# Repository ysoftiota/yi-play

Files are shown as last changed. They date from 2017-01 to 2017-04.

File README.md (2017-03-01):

# YSoft IOTA Play
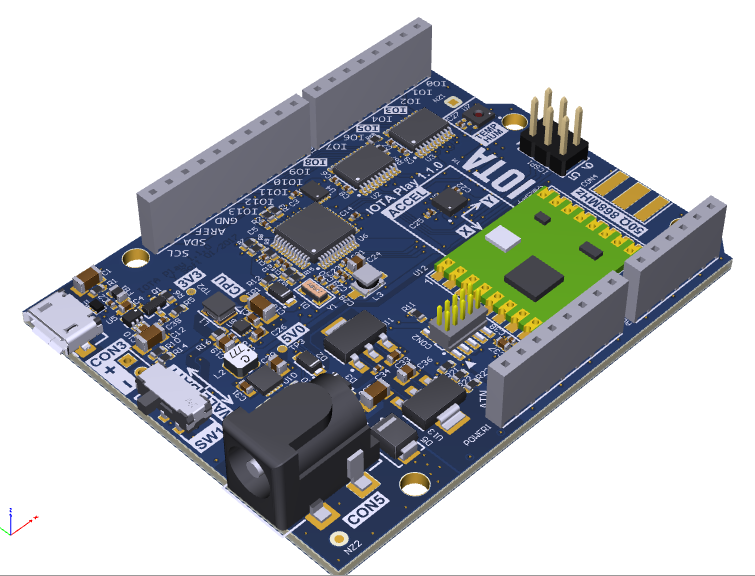
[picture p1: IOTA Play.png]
IOTA Play


## What is YSoft IOTA Play?

YSoft IOTA Play is [Arduino Zero](https://www.arduino.cc/en/Main/ArduinoBoardZero) ([Arduino M0](http://www.arduino.org/products/boards/arduino-m0)) clone with the following improvements:
* Two user LEDs
* Two user buttons
* Onboard Temperature + Humidity sensor [Silicon Labs SI7006-A20](https://www.silabs.com/products/sensors/humidity-sensors/Pages/si7013-20-21.aspx)
* Onboard 3 axis accelerometer [STM LIS3DE](http://www.st.com/en/mems-and-sensors/lis3de.html)
* Onboard crypto chip with ECC and RNG [Atmel ATECC508A](http://www.atmel.com/devices/atecc508a.aspx)
* Onboard ISM 868MHz transceiver [HopeRF RFM69](http://www.hoperf.com/rf_transceiver/modules/RFM69HW.html)
* 5V tolerant I/O on selected digital pins
  * Voltage level translator with possibility to use 5V output voltage using external pull-up (for CMOS logic)
* Enhanced power supplies
  * Optimized for battery operation - extremely low self-power consumption of power supplies
  * Designed for 2xAA, 2xAAA or other 3V alkaline cell operation (4V rechargeable lithium cells not supported)
  * <10uA complete board power consumption in standby (without power LEDs and peripheral voltages enabled)
  * 3.3V boost from 3V battery for core and peripherals
  * 3.3V peripheral voltage can be powered down in standby
  * 5V boost from 3V battery that can be powered down in standby
  * USB Host mode 5V supported in battery mode operation
* Manual switch between battery and USB/Power jack operation
* Most of functionality can be changed by onboard 0R resistors
  * Disable not needed peripherals
  * Disable not needed power supplies
  * Power consumption optimization
  * Set I/O pin for user application
* Additional SPI1 defined on pins 10,11,12,13 where Arduino UNO has got SPI

### Moreover:
* YSoft IOTA Play comes with configurable 3D printable box [How To](https://github.com/ysoftiota/yi-play/blob/master/Box/README.md)
* YSoft IOTA Play can be developed in Arduino IDE [How To](https://github.com/ysoftiota/yi-play-arduino)
* YSoft IOTA Play is open source and open hardware [Schematics](https://github.com/ysoftiota/yi-play/raw/master/IOTA_PlayBoard_1.1.0/Project%20Outputs%20for%20IOTA_PlayBoard_1.1.0/Schematic%20Print/IOTA_PlayBoard_1.1.0%20-%20Sche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), [3D PDF](https://github.com/ysoftiota/yi-play/raw/master/IOTA_PlayBoard_1.1.0/Project%20Outputs%20for%20IOTA_PlayBoard_1.1.0/3D%20View/IOTA_PlayBoard_1.1.0%20-%20Export%20PDF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), [PCB print](https://github.com/ysoftiota/yi-play/raw/master/IOTA_PlayBoard_1.1.0/Project%20Outputs%20for%20IOTA_PlayBoard_1.1.0/PCB%20Print/IOTA_PlayBoard_1.1.0%20-%20PCB%20Prin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), [Assembly drawing](https://github.com/ysoftiota/yi-play/raw/master/IOTA_PlayBoard_1.1.0/Project%20Outputs%20for%20IOTA_PlayBoard_1.1.0/PCB%20Print/IOTA_PlayBoard_1.1.0%20-%20Assembly%2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). See [IOTA_PlayBoard_1.1.0](https://github.com/ysoftiota/yi-play/tree/master/IOTA_PlayBoard_1.1.0) for complete PCB project.

# Limitations compared to Arduino Zero
* IOTA Play does not contain embedded EDBG debugger chip. [Atmel ICE debugger](http://www.atmel.com/tools/atatmel-ice.aspx) must be obtained separately if debugging is needed.
* LED(s) are on different pin, so use LED_BUILTIN and PIN_LED1 PIN_LED2 defines for accessing LEDs
* Maximum input voltage is 14V - however it starts as low as 5V
* Lower Amp rating of 5V (300mA) and 3.3V (200mA) voltage regulators which should be enough for normal applications. Power supplies are optimized for low-power battery operation, not for power hungry applications.
* Some pins are used by internal peripherals ([pin mapping](https://github.com/ysoftiota/yi-play/wiki/PinMapping), [pin mapping PDF](https://github.com/ysoftiota/yi-play/blob/master/IOTA_PlayBoard_1.1.0/IOTA%20Play%20board%201.1.0%20pin%20mapping.pdf)), therefore they cannot be used by anything else. However given peripheral can be disconnected by desoldering 0R resistors.
* Only one hardware serial port is supported and SerialUSB (defined as Serial) is used for Arduino monitor. If you need to access the hardware serial port then use SERIAL_PORT_HARDWARE define.

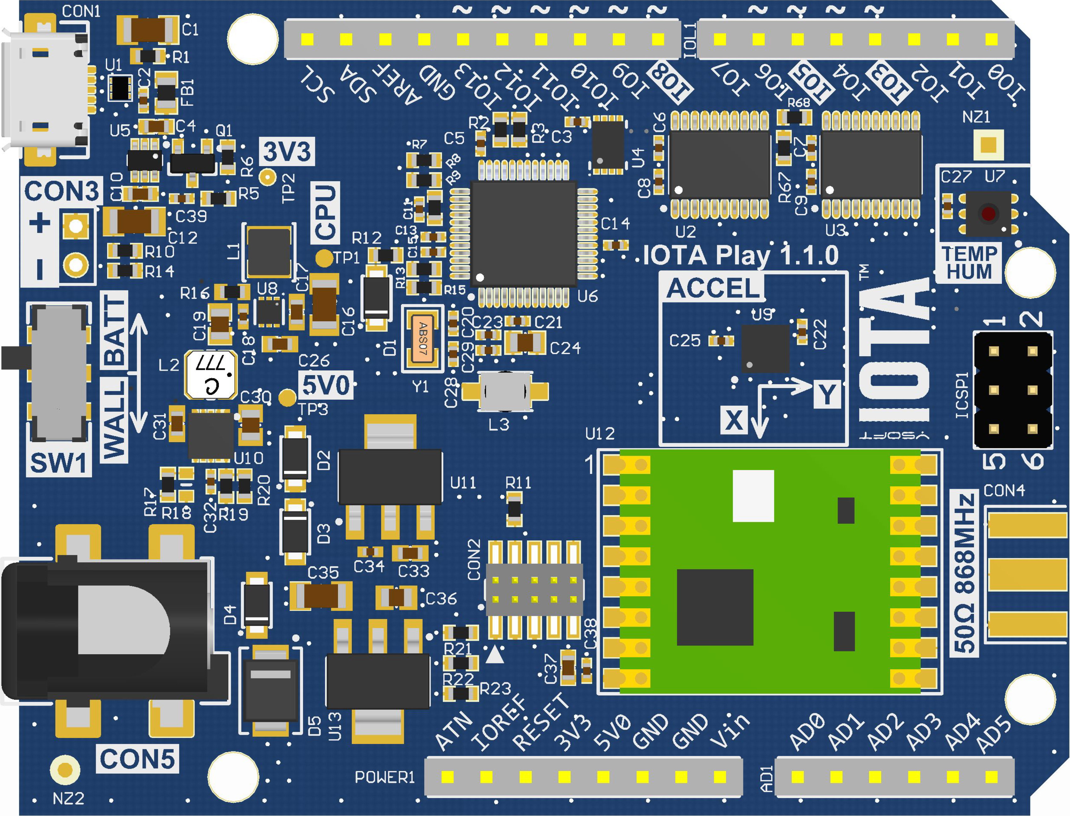
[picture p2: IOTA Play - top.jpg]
IOTA Play

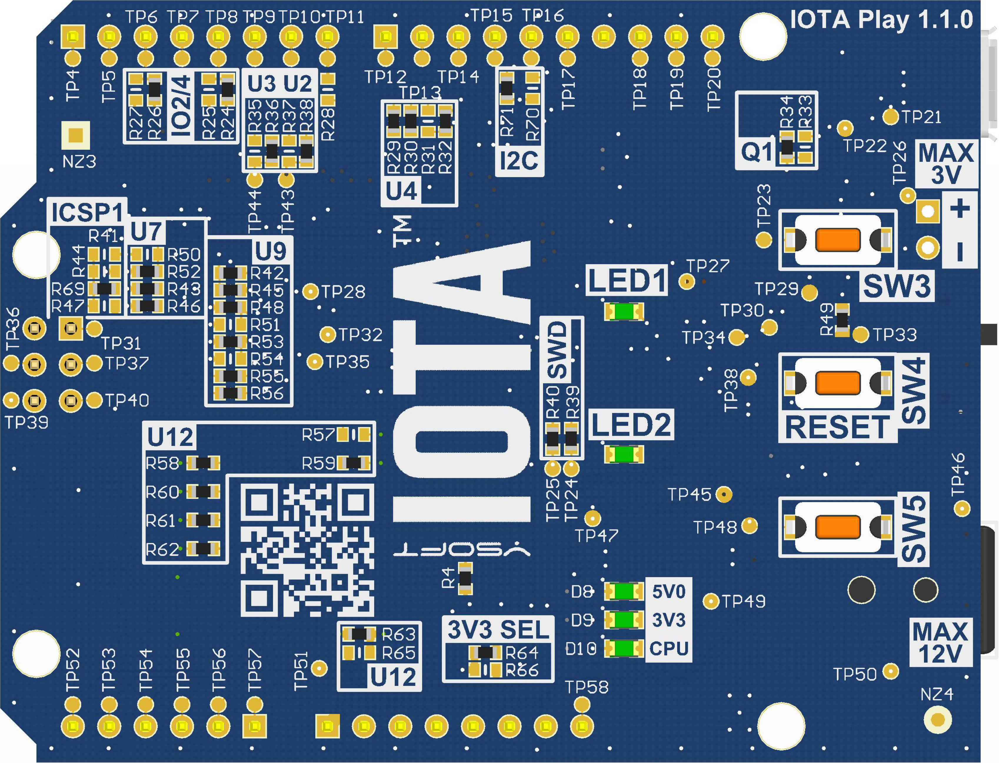
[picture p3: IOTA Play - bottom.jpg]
IOTA Play


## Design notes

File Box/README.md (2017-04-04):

# YSoft IOTA Play box
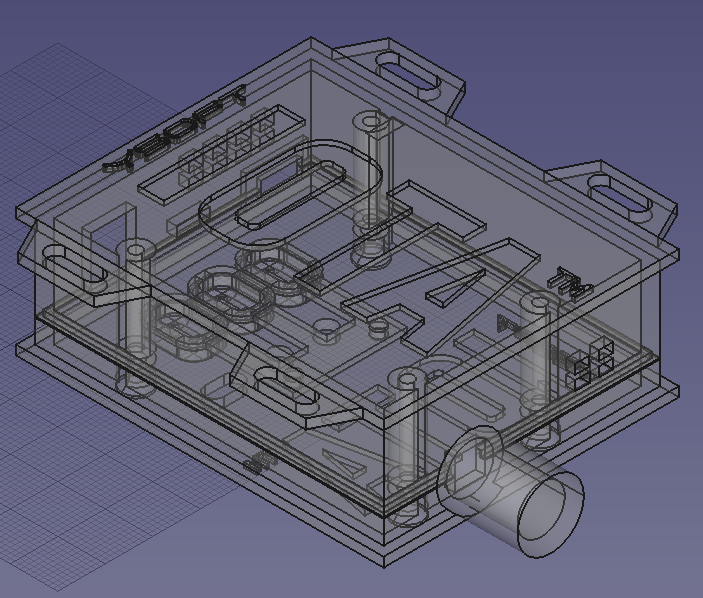
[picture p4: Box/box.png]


## Features
* The model is configurable - it contains all possible features for development or it can be used as a standalone box for outside use
  * configurable inner height
  * configurable spacers (for use with Arduino or prototyping shields)
  * buttons absent/present
  * led holes absent/present
  * logo absent/present
  * different connector holes absent/present
  * top/bottom mounting holes absent/present
* Printable on [YSoft be3D eDee](https://www.ysoft.com/en/be3d-edee-3dprinter) printers

## Manufacturing procedure
1. Download [stl/obj files](https://github.com/ysoftiota/yi-play/blob/master/Box/IOTA_Play_Box_1.1.zip) or export them using FreeCAD from [model](https://github.com/ysoftiota/yi-play/blob/master/Box/IOTA_Play_Box_1.1.FCStd). Please note that FreeCAD version 0.16 or higher is required.
1. Select the models to print in DeeControl, layout is recommended the following:
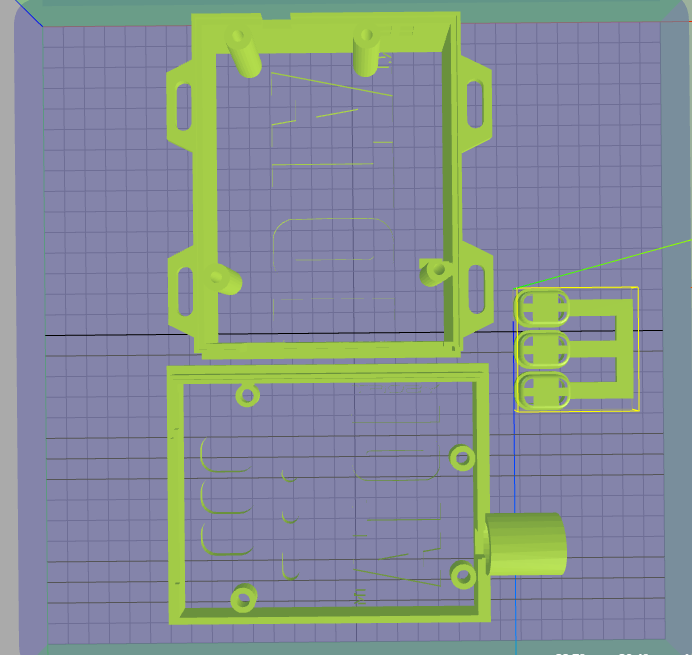
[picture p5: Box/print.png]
print

1. You can print either on Normal (150um) or Draft mode (200um)
1. Make sure you have supports off and that all the settings on the advanced tab are reset to default
1. Always thoroughly clean the print bed (by water and dry it afterwards) so that the box surface is nice and shiny
1. Apply the glue in uniform thin layer over the whole surface of the print bed. Make sure there are no spots without the glue because the large surfaces have tendencies to pick up.
1. The print will take 3-4h depending on quality selected
1. After printing it may be necessary to clean the buttons and button holes by a sharp knife so that the buttons move freely
1. If the buttons are not printed correctly, print them separately using slower speed or better quality.
1. You can glue the button holder on the centering pins or you can use soldering iron to melt them.
1. 4 screws are required. Screws [Bossard 2001225](https://eu.shop.bossard.com/mk/cz/10316/zavitorezne-srouby-vrtaci-srouby-zavitotvareci-srouby/srouby-do-termoplastu/bn-13576_srouby-pt-174-se-zapustnou-hlavou-s-kriz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) or longer for larger boxes [Bossard 3034352](https://eu.shop.bossard.com/mk/cz/10305/zavitorezne-srouby-vrtaci-srouby-zavitotvareci-srouby/srouby-do-termoplastu/bn-82427_srouby-se-zapustnou-hlavou-s-krizovou-dr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) are ideally suited.
1. Please remember to remove the white cover from the temperature/humidity sensor before use.
1. Enjoy your IOTA Play in the box

## Configuring the model
1. Open the FCStd file in FreeCad 0.16 or higher (in older versions you will not see the spreadsheet)
1. Open the model_parameters spread sheet from Combo View panel:
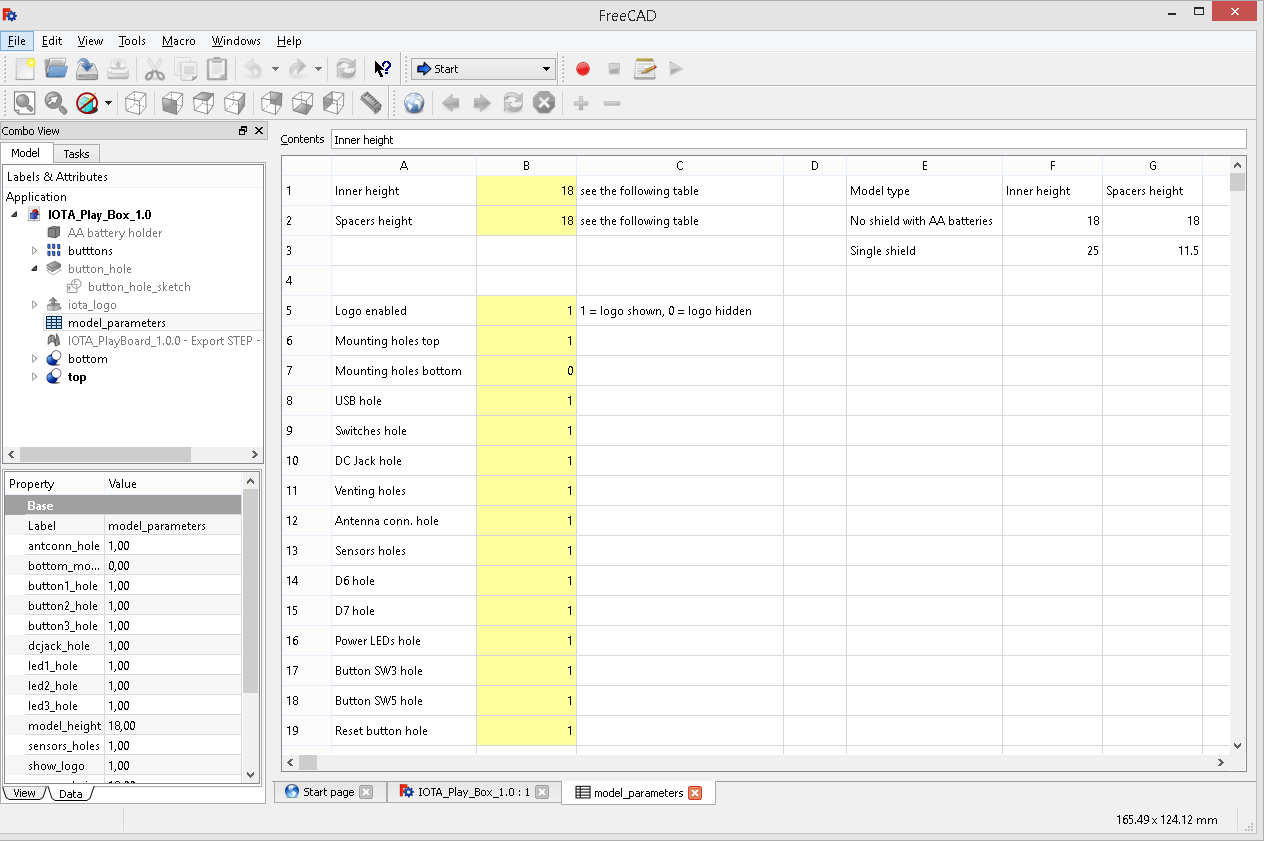
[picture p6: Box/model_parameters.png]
   
1. Select model height and which parts you need and which you don't. 1 means object enabled, 0 means object disabled.
1. Rewiew the changes you made, the model is transparent.
1. Click on 'top' part from Combo view (the part will turn green) and go to File -> Export. Select STL Mesh or Wavefront OBJ for the export format.
1. Repeat for 'bottom' and 'buttons' parts.
1. Follow the manufacturing procedure above

## Pictures
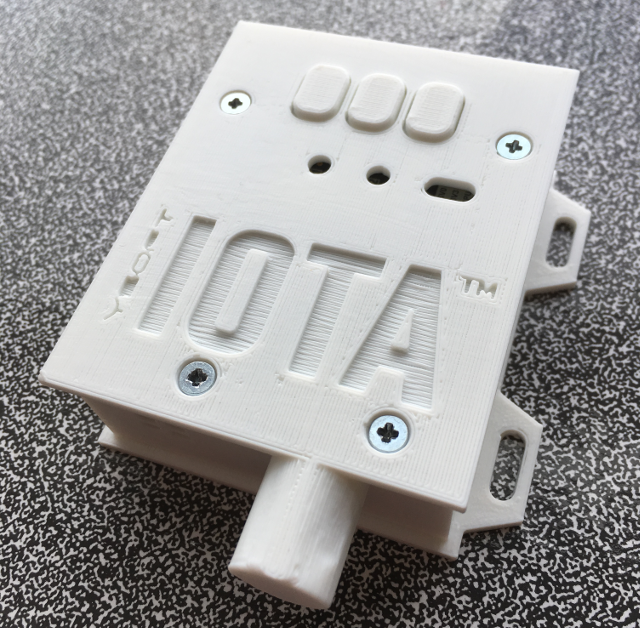
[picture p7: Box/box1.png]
 
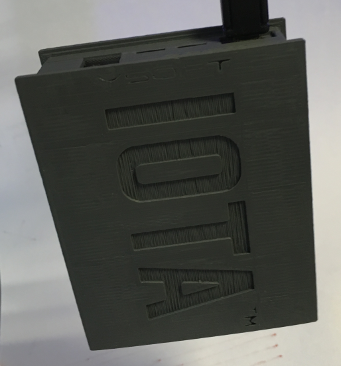
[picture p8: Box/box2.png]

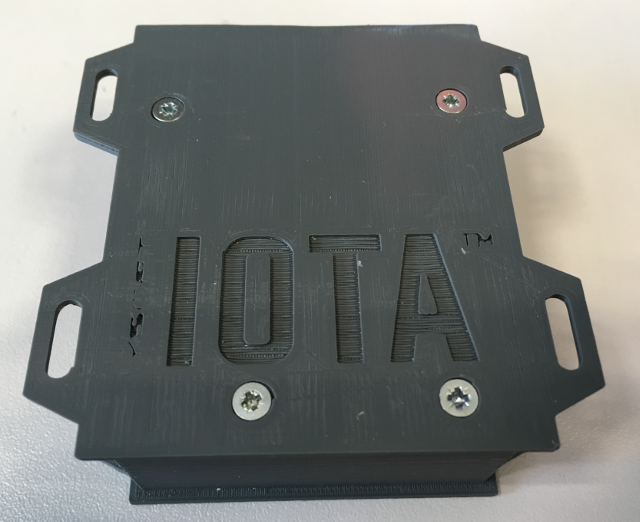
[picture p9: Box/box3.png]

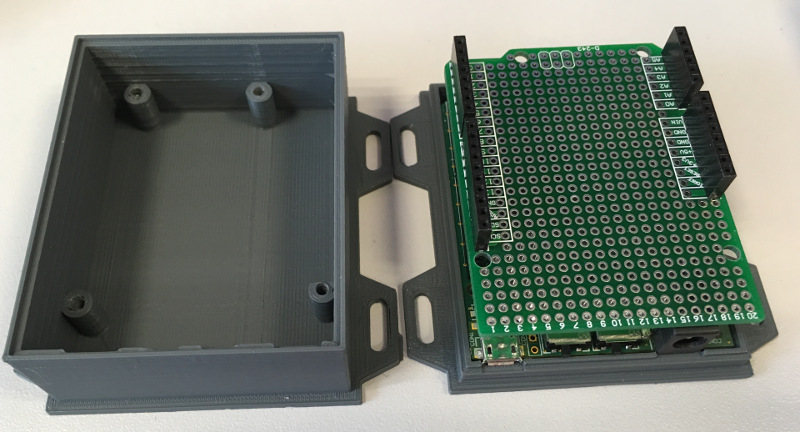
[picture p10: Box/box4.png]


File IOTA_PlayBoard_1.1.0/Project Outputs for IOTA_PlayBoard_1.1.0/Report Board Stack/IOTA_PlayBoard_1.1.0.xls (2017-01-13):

Board Stack Report
Stack Up |  | Layer Stack
Layer | Board Layer Stack | Name | Material | Thickness | Constant
1 |  | Top Paste
2 |  | Top Overlay
3 |  | Top Solder | Solder Resist | 0,010mm | 3,5
4 |  | Top Layer | Copper | 0,036mm
5 |  | Dielectric1 | IS400 - 2125 | 0,127mm | 4,2
6 |  | Internal Plane 1 | Copper | 0,036mm
7 |  | Dielectric 3 | IS400 | 1,200mm | 4,2
8 |  | Vcc Layer | Copper | 0,036mm
9 |  | Dielectric 4 | IS400 - 2125 | 0,127mm | 4,2
10 |  | Bottom Layer | Copper | 0,036mm
11 |  | Bottom Solder | Solder Resist | 0,010mm | 3,5
12 |  | Bottom Overlay
13 |  | Bottom Paste
 | Height : 1,618mm

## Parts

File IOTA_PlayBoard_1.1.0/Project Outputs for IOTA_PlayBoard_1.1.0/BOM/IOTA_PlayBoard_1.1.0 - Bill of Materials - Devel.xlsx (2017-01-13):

Designator | Comment | Description | Helios ID | Quantity | Footprint | DocumentName
AD1 | BL806G | Pinheader Female 6 pin 2.54mm | CON-BL806G | 1 | HDR1X06F | 01 - Connectors.SchDoc
C1 | 1nF/2kV | SMD Ceramic Capacitor 1206 1nF/2kV | CAP-1206 1nF/2kV | 1 | C-1206 | 01 - Connectors.SchDoc
C2, C3, C5, C6, C7, C8, C9, C11, C14, C15, C18, C21, C22, C23, C25, C27, C32, C38 | 100nF/16V | SMD Ceramic Capacitor 0402 100nF/16V | CAP-0402 100nF/16V | 18 | C-0402 | 01 - Connectors.SchDoc, 04 - Peripherals.SchDoc, 03 - CPU.SchDoc, 01 - Connectors.SchDoc, 01 - Connectors.SchDoc, 01 - Connectors.SchDoc, 01 - Connectors.SchDoc, 03 - CPU.SchDoc, 03 - CPU.SchDoc, 03 - CPU.SchDoc, 02 - Power.SchDoc, 03 - CPU.SchDoc, 04 - Peripherals.SchDoc, 01 - Connectors.SchDoc, 04 - Peripherals.SchDoc, 04 - Peripherals.SchDoc, 02 - Power.SchDoc, 04 - Peripherals.SchDoc
C4, C10, C31 | 2.2uF/16V/X5R | SMD Ceramic Capacitor 0603 2.2uF/16V/X5R | CAP-0603 2.2uF/16V/X5R | 3 | C-0603 | 02 - Power.SchDoc
C12, C16 | 100u/10V X5R | SMD Ceramic Capacitor 1206 100u/10V X5R | CAP-1206 100u/10V X5R | 2 | C-1206 | 01 - Connectors.SchDoc, 02 - Power.SchDoc
C13, C29, C34 | 1uF/10V/X5R | SMD Ceramic Capacitor 0402 1uF/10V/X5R | CAP-0402 1uF/10V/X5R | 3 | C-0402 | 03 - CPU.SchDoc, 01 - Connectors.SchDoc, 02 - Power.SchDoc
C17, C26, C33, C37 | 10uF/6.3V/X5R | SMD Ceramic Capacitor 0603 10uF/6.3V/X5R | CAP-0603 10uF/6.3V/X5R | 4 | C-0603 | 02 - Power.SchDoc, 02 - Power.SchDoc, 02 - Power.SchDoc, 04 - Peripherals.SchDoc
C19, C24, C30, C36 | 10u/10V | SMD Ceramic Capacitor 0805 10u/10V | CAP-0805 10u/10V | 4 | C-0805 | 02 - Power.SchDoc, 03 - CPU.SchDoc, 02 - Power.SchDoc, 02 - Power.SchDoc
C20, C28 | 22pF | SMD Ceramic Capacitor 0402 22pF | CAP-0402 22pF | 2 | C-0402 | 03 - CPU.SchDoc
C35 | 22uF/25V/X5R | SMD Ceramic Capacitor 1206 22uF/25V/X5R | CAP-1206 22u/25V/X5R | 1 | C-1206 | 02 - Power.SchDoc
C39 | 10nF/10V | SMD Ceramic Capacitor 0402 10nF/10V | CAP-0402 10nF/10V | 1 | C-0402 | 02 - Power.SchDoc
CON1 | 10104111-0001LF | Micro USB AB SMD | CON-10104111-0001LF | 1 | 10104111-0001LF | 01 - Connectors.SchDoc
CON2 | CH52102M100 | 2x5pin dual row male header 1.27 mm | CON-CH52102M100-0P | 1 | CH52102M100 | 01 - Connectors.SchDoc
CON3 | PAD1G02 | 1x2pin single row pads, 2.54mm | CON-PAD1G02 | 1 | HDR1X02S | 01 - Connectors.SchDoc
CON5 | PJ-002AH-SMT | Power Jack 2.1x5.5mm | CON-PJ-002AH-SMT | 1 | PJ-002AH-SMT | 01 - Connectors.SchDoc
D1, D2, D3, D4 | MBR140SFT | Schottky Power Rectifier MBR140SFT | DIO-MBR140SFT | 4 | SOD-123FL | 03 - CPU.SchDoc, 02 - Power.SchDoc, 02 - Power.SchDoc, 02 - Power.SchDoc
D5 | SM6T15A | Transil 15V | DIO-SM6T15A | 1 | D-SMB | 02 - Power.SchDoc
D8, D9, D10, LED1, LED2 | LED G | LED; SMD; 0805; zelená; 1.3-3mcd; 2.0x1.25x1,1mm; 120°; 1.9V; 2mA | DIO-KP-2012LSGC | 5 | LED-0805 GREEN | 03 - CPU.SchDoc
FB1 | BLM21PG221SN1D | Chip Ferrite Bead 220R/2A 0805 | IND-BLM21PG221SN1D | 1 | FB-0805 | 01 - Connectors.SchDoc
ICSP1 | S2G06 | 2x6pin dual row header, 2.54mm | CON-S2G06 | 1 | HDR2X06 | 01 - Connectors.SchDoc
IOH1 | BL810G | Pinheader Female 10 pin 2.54mm | CON-BL810G | 1 | HDR1X10F | 01 - Connectors.SchDoc
IOL1, POWER1 | BL808G | Pinheader Female 8 pin 2.54mm | CON-BL808G | 2 | HDR1X08F | 01 - Connectors.SchDoc
L1 | SRN3015-4R7M | Shielded inductor 4.7uH/1.2A 3x3mm | IND-SRN3015-4R7M | 1 | TLU-SRN3015 | 02 - Power.SchDoc
L2 | LPS3015-152MRC | Shielded inductor 1.5uH/1.3A 3x3mm | IND-LPS3015-152MRC | 1 | LPS3015 | 02 - Power.SchDoc
L3 | LQH32CN100K23L | Unshielded Wirewound Inductor 10uH/300mA/572mOhm 3.2x2.5mm | IND-LQH32CN100K23L | 1 | LQH32C | 03 - CPU.SchDoc
NZ1, NZ3 | Fiducial Rectangle | Fiducial Rectangle | x004 | 2 | Fiducial Rectangle | 01 - Connectors.SchDoc
NZ2, NZ4 | Fiducial Circle | Fiducial Circle | x005 | 2 | Fiducial Circle | 01 - Connectors.SchDoc
Q1 | FDV303N | N-channel Digital FET 25 V, 680 mA | TRA-FDV303N | 1 | SOT23-3L | 02 - Power.SchDoc
R1 | 100R 1% | SMD Resistor 0603 100R 1% | RES-0603 100R 1% | 1 | R-0603 | 01 - Connectors.SchDoc
R2, R3, R7, R8, R11, R12 | 10k | SMD Resistor 0603 10k | RES-0603 10k | 6 | R-0603 | 01 - Connectors.SchDoc, 01 - Connectors.SchDoc, 03 - CPU.SchDoc, 03 - CPU.SchDoc, 01 - Connectors.SchDoc, 03 - CPU.SchDoc
R4, R24, R26, R29, R30, R32, R34, R36, R38, R39, R40, R42, R43, R45, R46, R48, R49, R52, R53, R55, R56, R58, R59, R60, R61, R62, R63, R64, R69, R71 | 0R | SMD Resistor 0603 0R | RES-0603 0R | 30 | R-0603 | 01 - Connectors.SchDoc, 01 - Connectors.SchDoc, 01 - Connectors.SchDoc, 04 - Peripherals.SchDoc, 04 - Peripherals.SchDoc, 04 - Peripherals.SchDoc, 02 - Power.SchDoc, 01 - Connectors.SchDoc, 01 - Connectors.SchDoc, 03 - CPU.SchDoc, 03 - CPU.SchDoc, 04 - Peripherals.SchDoc, 04 - Peripherals.SchDoc, 04 - Peripherals.SchDoc, 04 - Peripherals.SchDoc, 04 - Peripherals.SchDoc, 02 - Power.SchDoc, 04 - Peripherals.SchDoc, 04 - Peripherals.SchDoc, 04 - Peripherals.SchDoc, 04 - Peripherals.SchDoc, 04 - Peripherals.SchDoc, 04 - Peripherals.SchDoc, 04 - Peripherals.SchDoc, 04 - Peripherals.SchDoc, 04 - Peripherals.SchDoc, 04 - Peripherals.SchDoc, 01 - Connectors.SchDoc, 01 - Connectors.SchDoc, 01 - Connectors.SchDoc
R5, R6, R20 | 887k 1% | SMD Resistor 0603 887k 1% | RES-0603 887k 1% | 3 | R-0603 | 02 - Power.SchDoc
R9, R16 | 470R | SMD Resistor 0603 470R | RES-0603 470R | 2 | R-0603 | 03 - CPU.SchDoc, 02 - Power.SchDoc
R10, R17 | 1.87M 1% | SMD Resistor 0603 1.87M 1% | RES-0603 1.87M 1% | 2 | R-0603 | 02 - Power.SchDoc
R13, R15, R22, R23 | 1k 1% | SMD Resistor 0603 1k 1% | RES-0603 1k 1% | 4 | R-0603 | 03 - CPU.SchDoc
R14 | 604k 1% | SMD Resistor 0603 604k 1% | RES-0603 604k 1% | 1 | R-0603 | 02 - Power.SchDoc
R19 | 100k 1% | SMD Resistor 0603 100k 1% | RES-0603 100k 1% | 1 | R-0603 | 02 - Power.SchDoc
R21 | 1.5k | SMD Resistor 0603 1k5 | RES-0603 1k5 | 1 | R-0603 | 03 - CPU.SchDoc
R67, R68 | 200k | SMD Resistor 0603 200k | RES-0603 200k | 2 | R-0603 | 01 - Connectors.SchDoc
SW1 | JS202011JAQN | Slide Switch DPDT Surface Mount, Right Angle | SWI-JS202011JAQN | 1 | JS202011JAQN | 02 - Power.SchDoc
SW3, SW4, SW5 | DTSM31N | SMT tactile switch, 2 pin | SWI-DTSM31N | 3 | DTSM31N | 03 - CPU.SchDoc
U1 | TPD4S012DRY | 4-Channel USB ESD Solution with Power Clamp | IC-TPD4S012DRYR | 1 | DRY6 | 01 - Connectors.SchDoc
U2, U3 | LSF0108PWR | 8-Bit Bidirectional Voltage-Level Translator For Open-Drain And Push-Pull Application | IC-LSF0108PWR | 2 | TSOP65P640X120-20L | 01 - Connectors.SchDoc
U4 | ATECC508A | CryptoAuthentication Device with 10Kb EEPROM | IC-ATECC508A-MAHDA-S | 1 | SON50P300X60_HS-9N | 04 - Peripherals.SchDoc
U5 | SIP32431DR3 | 1 A Slew Rate Controlled Load Switch with Reverse Blocking SOT-363 | IC-SIP32431DR3-T1GE3 | 1 | SOT65P210X110-6L | 02 - Power.SchDoc
U6 | ATSAMD21G18A-AUT | ARM® Cortex®-M0+ SAM D21G Microcontroller IC 32-Bit 48MHz 256KB (256K x 8) FLASH 48-TQFP (7x7) | IC-ATSAMD21G18A-AUT | 1 | TSQFP50P900X900X160-48L | 03 - CPU.SchDoc
U7 | SI7006-A20 | I2C Humidity and Temperature Sensor | IC-SI7006-A20-IM1 | 1 | DFN100P300X300X60_HS-7N - duplicate | 04 - Peripherals.SchDoc
U8 | TPS610986 | Ultra-Low Quiescent Current Synchronous Boost with Integrated Load Switch | IC-TPS610986DSE | 1 | SON50P150X80-6N | 02 - Power.SchDoc
U9 | LIS3DETR | Accelerometer X, Y, Z | IC-LIS3DETR | 1 | PQFN50P300X300X100-16N | 04 - Peripherals.SchDoc
U10 | TPS63030DSK | High Efficient Single Inductor Buck-Boost Converter with 1-A Switches | IC-TPS63030DSKR | 1 | DSK10-2000X1200TP_V | 02 - Power.SchDoc
U11 | AP7361-33E | Linear Voltage Regulator IC Positive Fixed 1 Output 3.3V 1A SOT-223 | IC-AP7361-33E-13 | 1 | SOT230P700X180-4N | 02 - Power.SchDoc
U12 | RFM69HW-868 | RFM69HW ISM TRANSCEIVER MODULE | RF-RFM69HW-868S2 | 1 | RFM69HW-XXXS2 | 04 - Peripherals.SchDoc
U13 | NCP1117LPST50 | 1.0A, 5V Low-Dropout Positive Voltage Regulator | IC-NCP1117LPST50T3G | 1 | SOT230P700X180-4N | 02 - Power.SchDoc
Y1 | 32768Hz | Crystal 32768 Hz SMD, package 3.2x1.5mm | CRY-ABS07-32.768KHZ-T | 1 | ABS07 | 03 - CPU.SchDoc

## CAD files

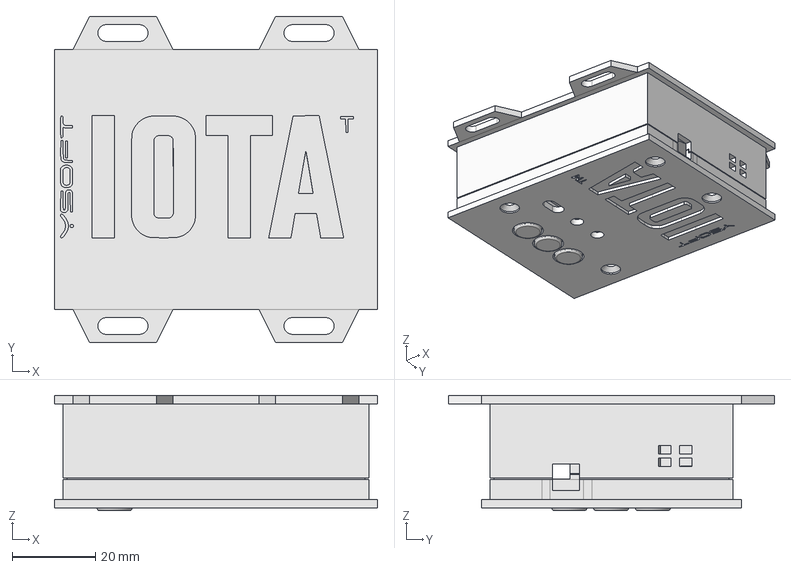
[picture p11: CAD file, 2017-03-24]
Box/IOTA_Play_Box_1.1.FCStd
77.4 x 78.2 x 27.6 mm
butttons
bottom
top

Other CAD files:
Box/IOTA_Play_Box_1.0.FCStd

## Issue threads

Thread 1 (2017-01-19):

QR code is in negative colors and cannot be read

setnicka, 2017-01-19:
The QR code at the bottom of the board is in negative colors.

Many QR code readers (for example popular [Barcode Scanner](https://play.google.com/store/apps/details?id=com.google.zxing.client.android), [QR & Barcode Scanner](https://play.google.com/store/apps/details?id=com.gamma.scan) for Android and many others) cannot read inverted QR codes.

QR code should be printed in inverted colors - blue on white background.

And maybe link should be https://github.com/ysoftiota/yi-play (not only https://github.com/ysoftiota).

VelkyVenik, 2017-01-19:
I have no experiences with QR code readers, mine just works :) But I agree with the link, that it should be https://github.com/ysoftiota/yi-play

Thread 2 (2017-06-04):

Thermometer example

borissuska, 2017-06-04:
#import <i2cdetect.h> is not necessary on line 10.

Is `data[3]`correct on line 48? The array is defined as `unsigned int data[2];` on line 27.

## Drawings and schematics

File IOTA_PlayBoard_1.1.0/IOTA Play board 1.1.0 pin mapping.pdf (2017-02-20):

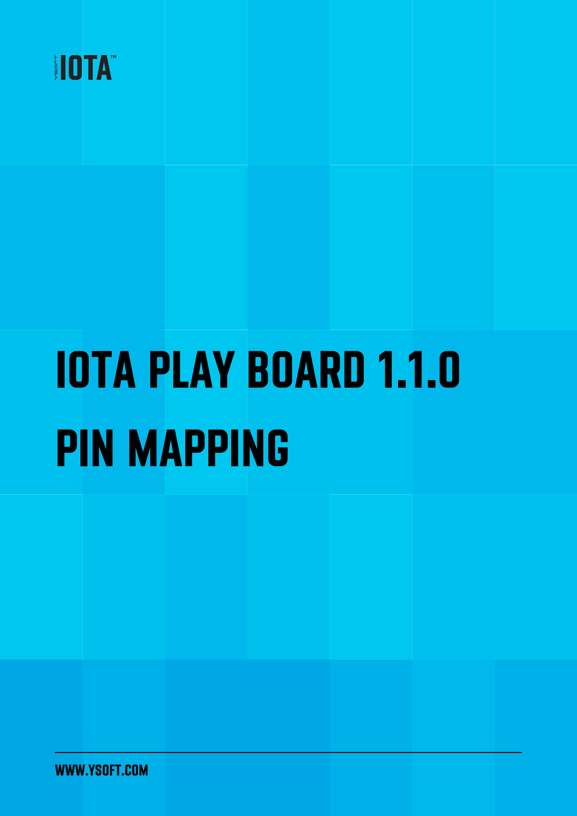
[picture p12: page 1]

# IOTA PLAY BOARD 1.1.0 PIN MAPPING

## WWW.YSOFT.COM

CONTENT 1 | Arduino Connectors

3

### 2 SPI Connector

5

### 3 IOTA Play specific

6

### 4 Complete PIN mapping

7

# 1 ARDUINO CONNECTORS

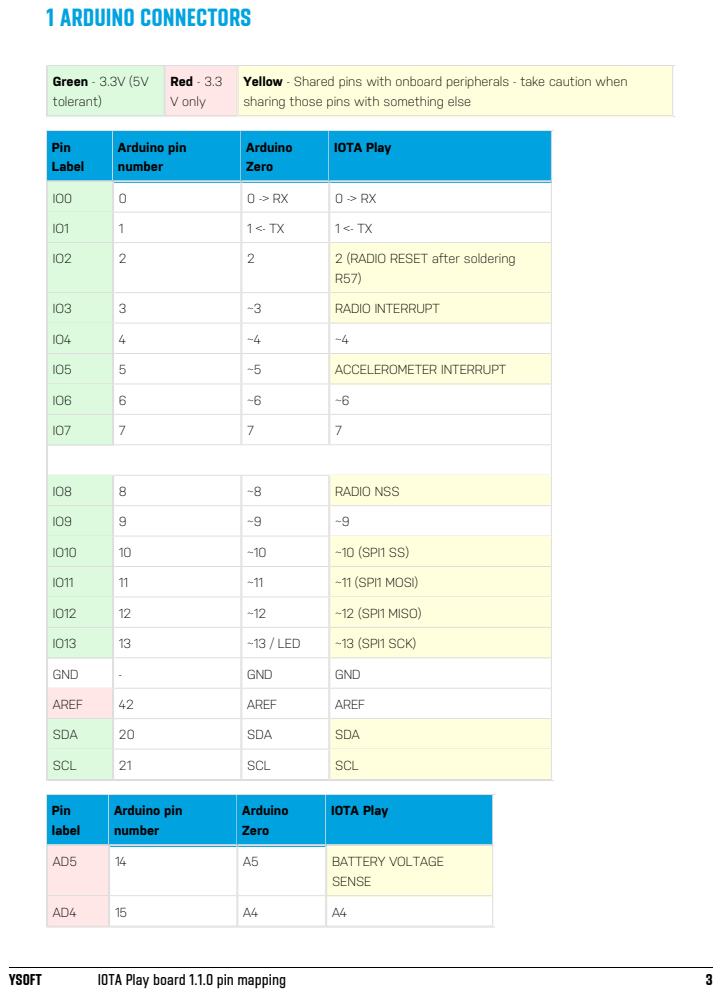
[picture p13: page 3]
YSOFT; IOTA Play board 1.1.0 pin mapping; Green - 3.3V (5V; tolerant); Red - 3.3; V only; Pin; Label; Arduino pin; number; Arduino; Zero; IOTA Play; 2 (RADIO RESET after soldering; RADIO INTERRUPT; ACCELEROMETER INTERRUPT; RADIO NSS; ~10 (SPI1 SS); ~11 (SPI1 MOSI); ~12 (SPI1 MISO); ~13 / LED; ~13 (SPI1 SCK); GND; AREF; SDA; SCL; label; BATTERY VOLTAGE; SENSE

Yellow - Shared pins with onboard peripherals - take caution when
sharing those pins with something else

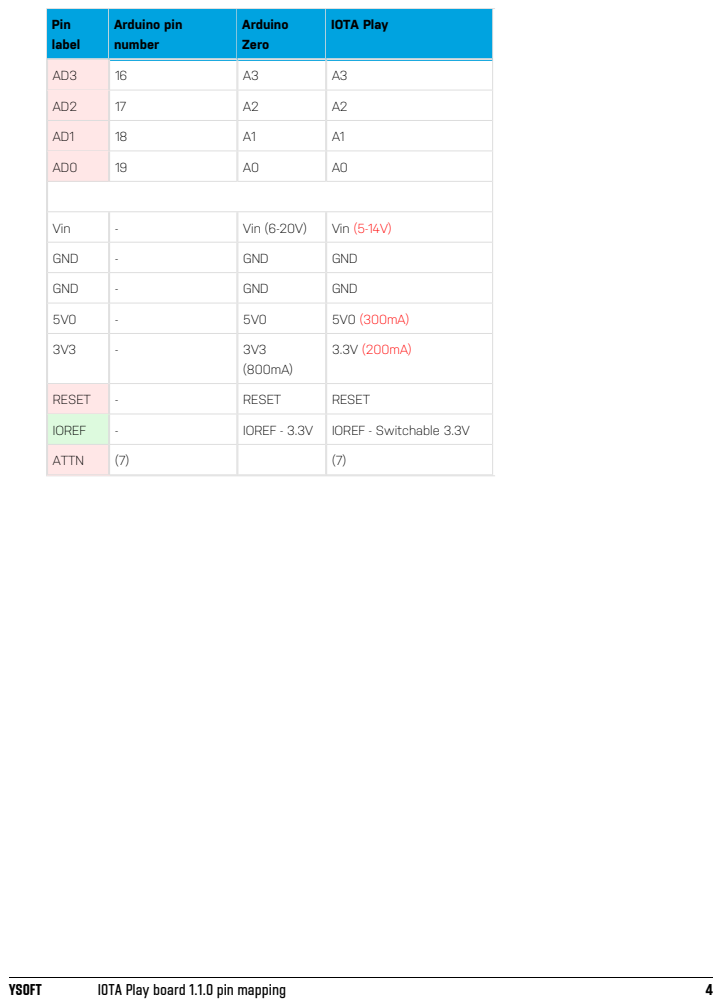
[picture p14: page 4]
YSOFT; IOTA Play board 1.1.0 pin mapping; Pin; label; Arduino pin; number; Arduino; Zero; IOTA Play; Vin; Vin (6-20V); Vin (5-14V); GND; RESET; IOREF; IOREF - 3.3V; IOREF - Switchable 3.3V; ATTN

# 2 SPI CONNECTOR

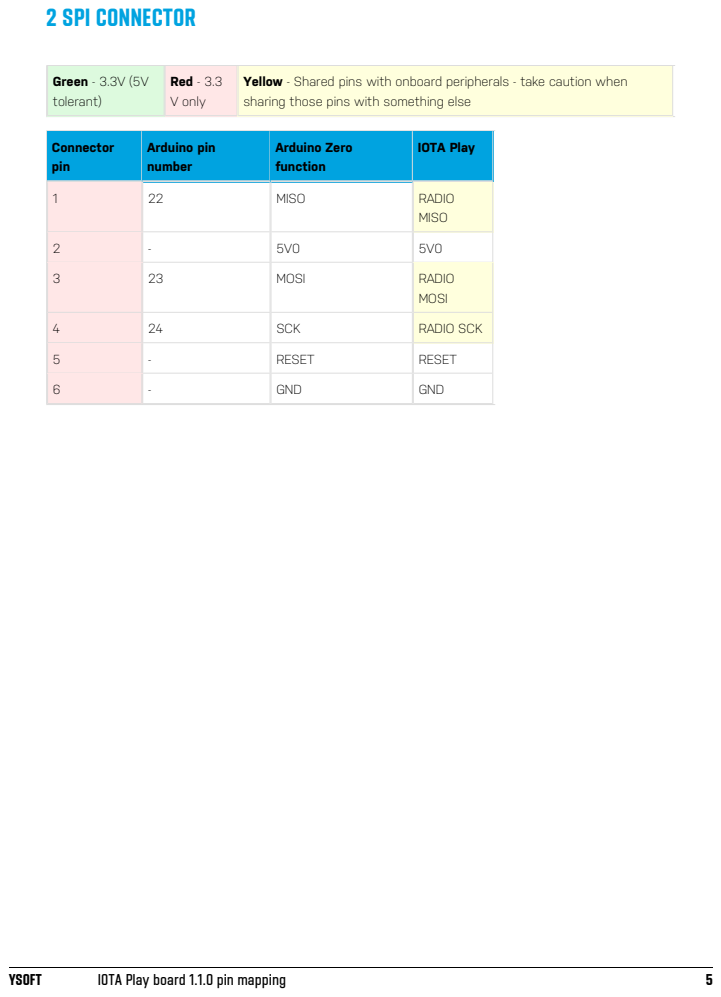
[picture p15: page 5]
YSOFT; IOTA Play board 1.1.0 pin mapping; Green - 3.3V (5V; tolerant); Red - 3.3; V only; Connector; pin; Arduino pin; number; Arduino Zero; function; IOTA Play; MISO; RADIO; MOSI; SCK; RADIO SCK; RESET; GND

Yellow - Shared pins with onboard peripherals - take caution when
sharing those pins with something else

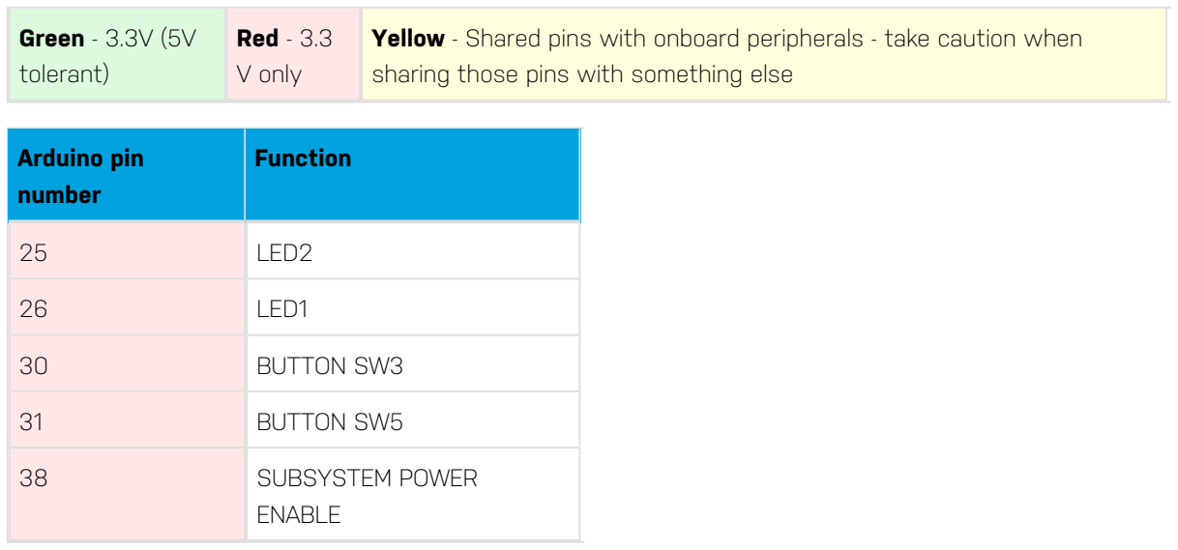
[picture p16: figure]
Green - 3.3V (5V; tolerant); Red - 3.3; V only; sharing those pins with something else; Arduino pin; number; Function; LED2; LED1; BUTTON SW3; BUTTON SW5; SUBSYSTEM POWER; ENABLE

YSOFT | IOTA Play board 1.1.0 pin mapping | 6

# 3 IOTA PLAY SPECIFIC

Yellow - Shared pins with onboard peripherals - take caution when

# 4 COMPLETE PIN MAPPING

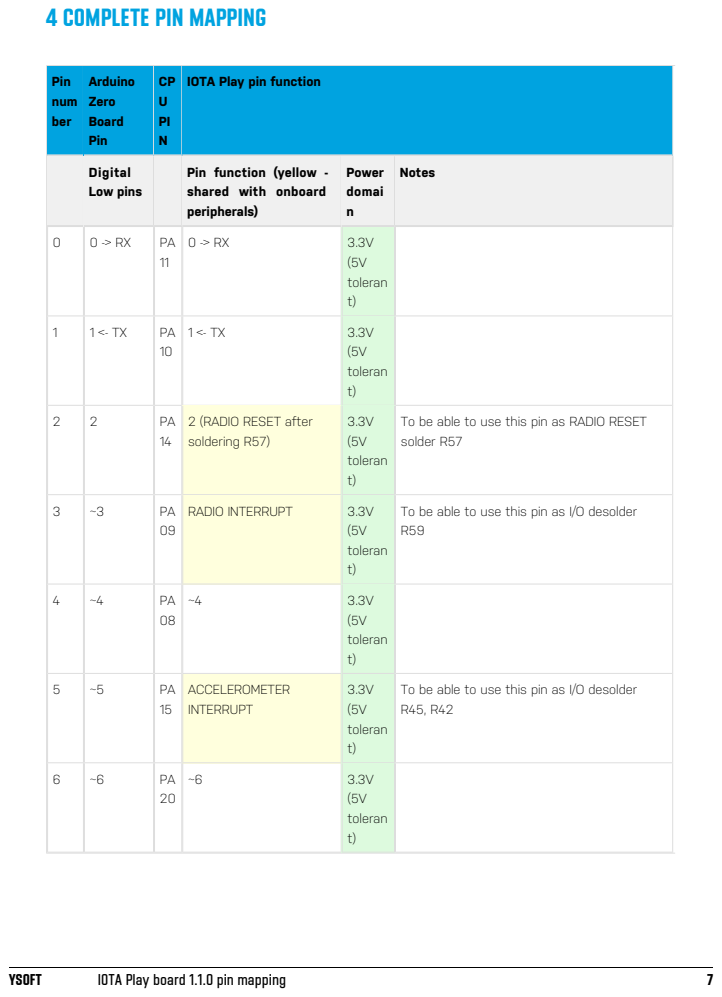
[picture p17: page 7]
YSOFT; IOTA Play board 1.1.0 pin mapping; Pin; num; ber; Arduino; Zero; Board; IOTA Play pin function; Digital; Low pins; Power; domai; Notes; toleran; 2 (RADIO RESET after; soldering R57); RADIO INTERRUPT; ACCELEROMETER; INTERRUPT

Pin function (yellow -
shared with onboard
peripherals)

To be able to use this pin as RADIO RESET
solder R57

To be able to use this pin as I/O desolder

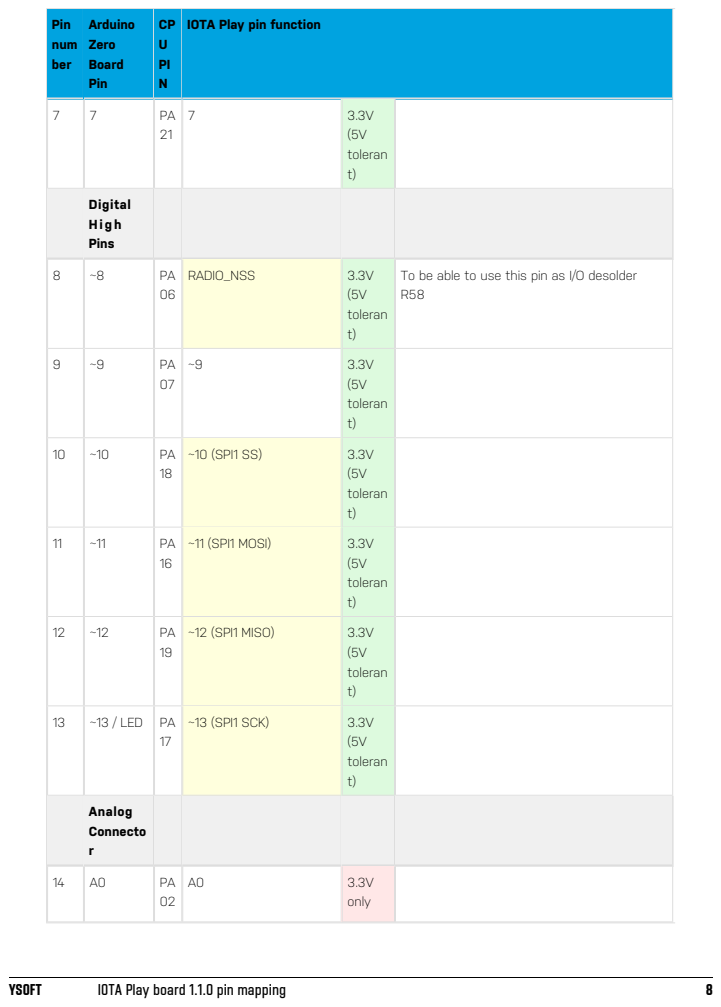
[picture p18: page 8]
YSOFT; IOTA Play board 1.1.0 pin mapping; num; ber; Zero; Board; Pin; IOTA Play pin function; toleran; Digital; High; Pins; RADIO_NSS; ~10 (SPI1 SS); ~11 (SPI1 MOSI); ~12 (SPI1 MISO); ~13 / LED; ~13 (SPI1 SCK); Analog; Connecto; only

To be able to use this pin as I/O desolder

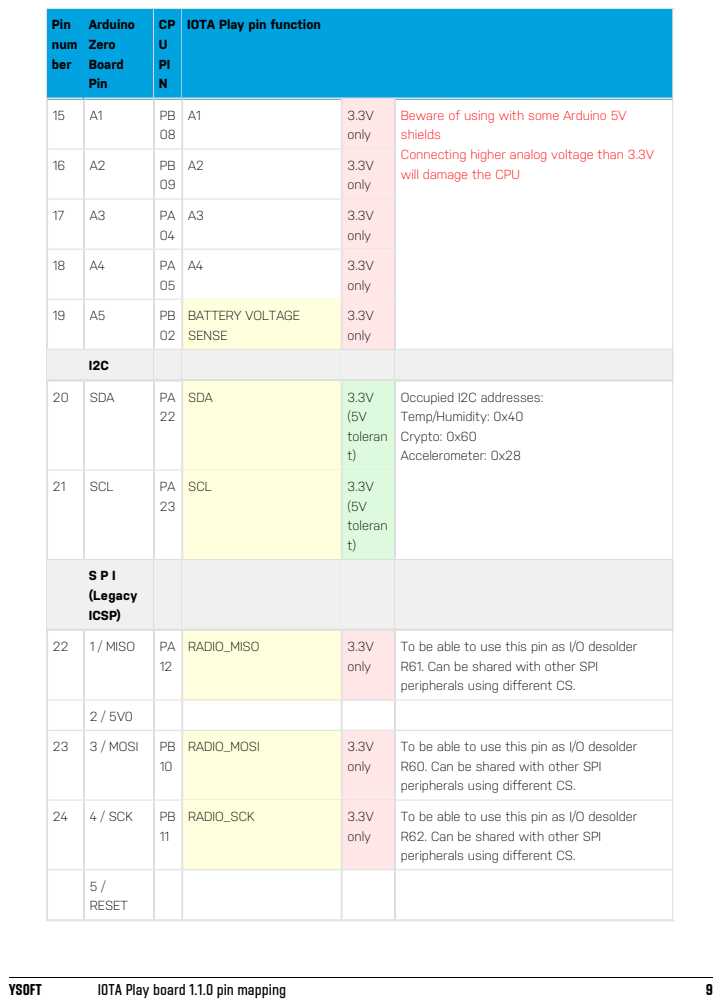
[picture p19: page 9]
YSOFT; IOTA Play board 1.1.0 pin mapping; num; ber; Zero; Board; Pin; IOTA Play pin function; only; BATTERY VOLTAGE; SENSE; SDA; toleran; Occupied I2C addresses:; Temp/Humidity: 0x40; Crypto: 0x60; Accelerometer: 0x28; SCL; S P I (Legacy; ICSP); 1 / MISO; RADIO_MISO; 3 / MOSI; RADIO_MOSI; 4 / SCK; RADIO_SCK; RESET

Beware of using with some Arduino 5V
shields
Connecting higher analog voltage than 3.3V
will damage the CPU

To be able to use this pin as I/O desolder
R61. Can be shared with other SPI
peripherals using different CS.

R60. Can be shared with other SPI

R62. Can be shared with other SPI

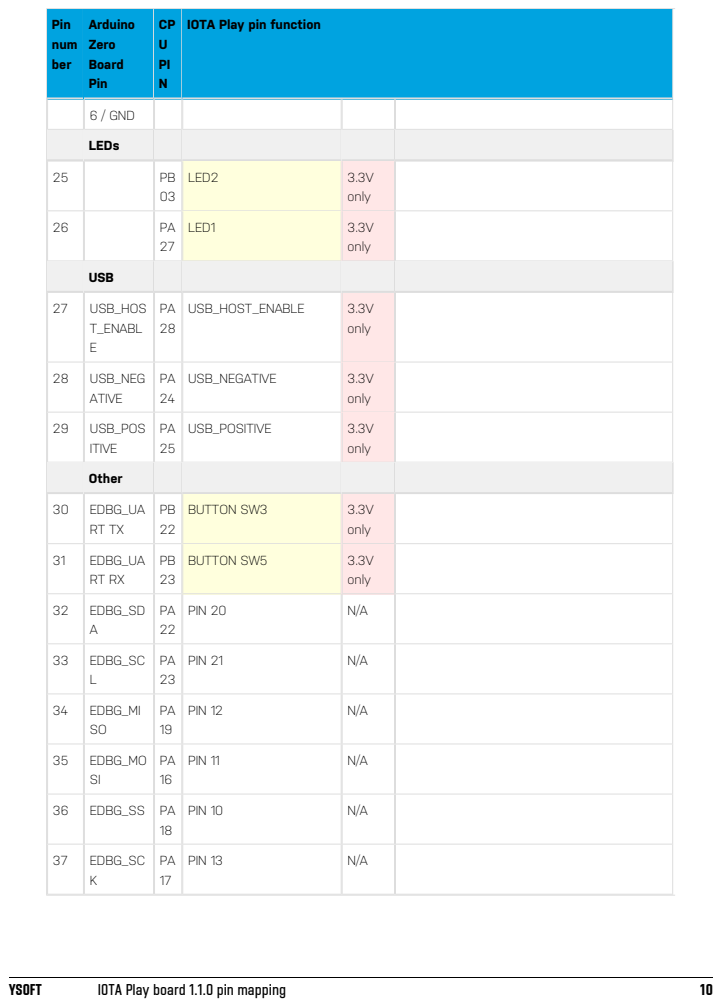
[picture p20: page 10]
YSOFT; IOTA Play board 1.1.0 pin mapping; num; ber; Zero; Board; Pin; IOTA Play pin function; 6 / GND; LEDs; LED2; only; LED1; USB; USB_HOS; T_ENABL; USB_HOST_ENABLE; USB_NEG; ATIVE; USB_NEGATIVE; USB_POS; ITIVE; USB_POSITIVE; Other; EDBG_UA; BUTTON SW3; BUTTON SW5; EDBG_SD; PIN 20; EDBG_SC; PIN 21; EDBG_MI; PIN 12; EDBG_MO; PIN 11; EDBG_SS; PIN 10; PIN 13

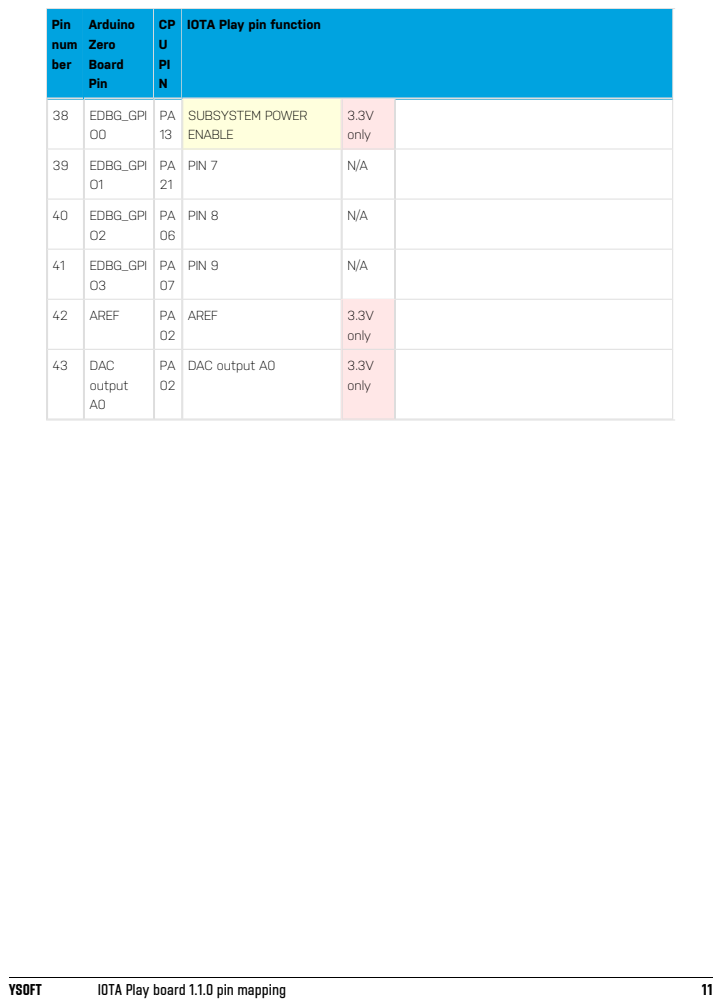
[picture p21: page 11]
YSOFT; IOTA Play board 1.1.0 pin mapping; EDBG_GPI; PIN 7; PIN 8; PIN 9; AREF; only; DAC; output; DAC output A0

num ber | Zero Board Pin | CP U PI N | IOTA Play pin function

SUBSYSTEM POWER ENABLE | | 3.3V only

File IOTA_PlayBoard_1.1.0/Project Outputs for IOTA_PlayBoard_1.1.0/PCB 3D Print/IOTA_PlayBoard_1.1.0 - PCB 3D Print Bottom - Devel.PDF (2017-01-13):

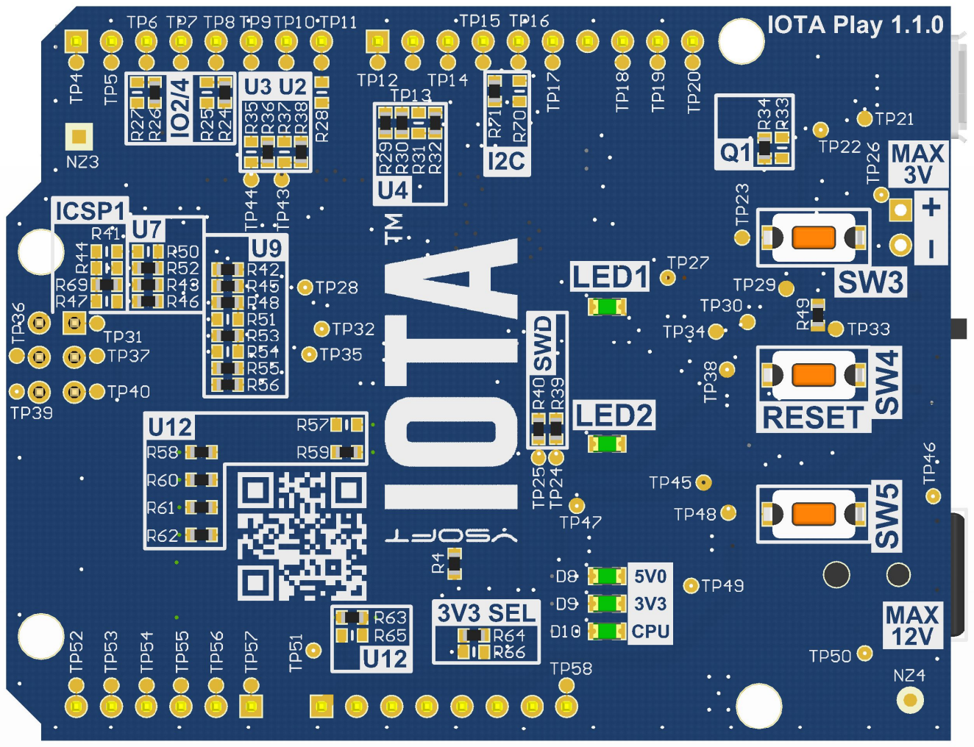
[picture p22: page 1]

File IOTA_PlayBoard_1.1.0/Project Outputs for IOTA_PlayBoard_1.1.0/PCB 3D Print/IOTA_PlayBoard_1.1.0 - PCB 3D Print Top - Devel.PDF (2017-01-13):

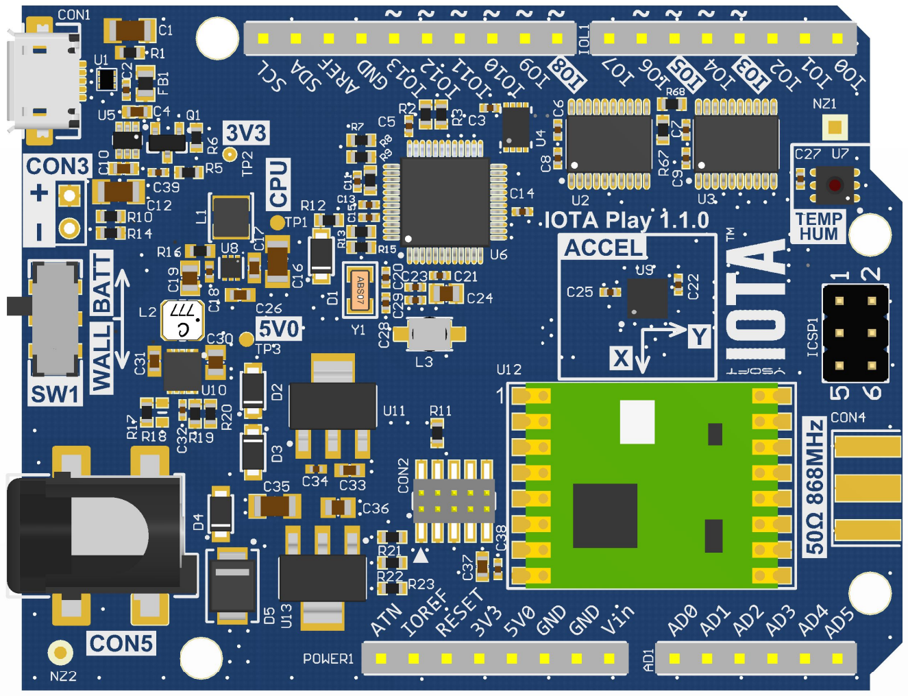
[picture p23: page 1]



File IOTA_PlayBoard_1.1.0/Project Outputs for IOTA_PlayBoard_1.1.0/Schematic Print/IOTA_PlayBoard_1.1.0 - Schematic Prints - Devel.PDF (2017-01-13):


Size: A4 | Number: 1 | Revision: 1.1.0
Date: 13.1.2017 Time: 13:55:04 | | Sheet of




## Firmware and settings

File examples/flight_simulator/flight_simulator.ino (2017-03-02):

#include "Wire.h"
#include "I2Cdev.h"
#include "YiPlayRF.h"

#define Addr 0x28


byte data[3];

void setup() {
  Wire.begin();
  SerialUSB.begin(115200);
  //wait for serial connection
 // while (!SerialUSB);

  Wire.beginTransmission(Addr);
  Wire.write(0x20);
  Wire.write(0x07 | (0x02 << 4));
  Wire.endTransmission();
  
  setupRadio(66, 2, NULL);
}

void loop() {
  Wire.beginTransmission(Addr);
  Wire.write(0x28 | 0x80);
  // Stop I2C transmission
  Wire.endTransmission();
  delay(50); 

  Wire.requestFrom(Addr, 6);
  if (Wire.available() == 6)
  {
    Wire.read();
    data[0] = Wire.read(); 
    Wire.read();
    data[1] = Wire.read();
    Wire.read();
    data[2] = Wire.read(); 

    radioSend(1, data);    
  }


}

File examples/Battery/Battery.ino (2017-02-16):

/*
  Battery sense example.
*/
#define Serial SerialUSB
#define BATTERY_SENSE_PIN A5  // select the input pin for the battery sense point

#define ANALOG_RES 12

void setup() {
  Serial.begin(115200);
  analogReadResolution(ANALOG_RES);
  analogReference(AR_INTERNAL1V0);

  //wait for serial connection
  while (!Serial);

}

void loop() {
  float sensorValue = (2474/604) * (float)analogRead(BATTERY_SENSE_PIN)/(4096);
  Serial.print("Battery sense value: ");
  Serial.println(sensorValue);

  delay(500);
}

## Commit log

2017-01-13 First release IOTA PlayBoard v1.1.0
    [01 - Connectors.SchDoc, 02 - Power.SchDoc, 03 - CPU.SchDoc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]
2017-01-13 Update filename of OutJob
    [IOTA_PlayBoard_1.1.0.PrjPcb]
2017-01-14 IOTA Play box data
    [IOTA_Play_Box.FCStd]
2017-01-14 FreeCad file is missing model configuration spreadsheet
    [IOTA_Play_Box.FCStd, IOTA_Play_Box_1.0.FCStd]
2017-01-14 LED definitions update
2017-02-16 YI-Play board Arduino examples
2017-02-20 PIN mapping PDF
2017-02-20 link to PIN mapping PDF
2017-03-01 Typo in power supplies
2017-03-24 Box for YSoft IOTA Play 1.1.0
    [IOTA_Play_Box_1.1.FCStd]
2017-04-04 New buttons, antenna cover and fixed logo
